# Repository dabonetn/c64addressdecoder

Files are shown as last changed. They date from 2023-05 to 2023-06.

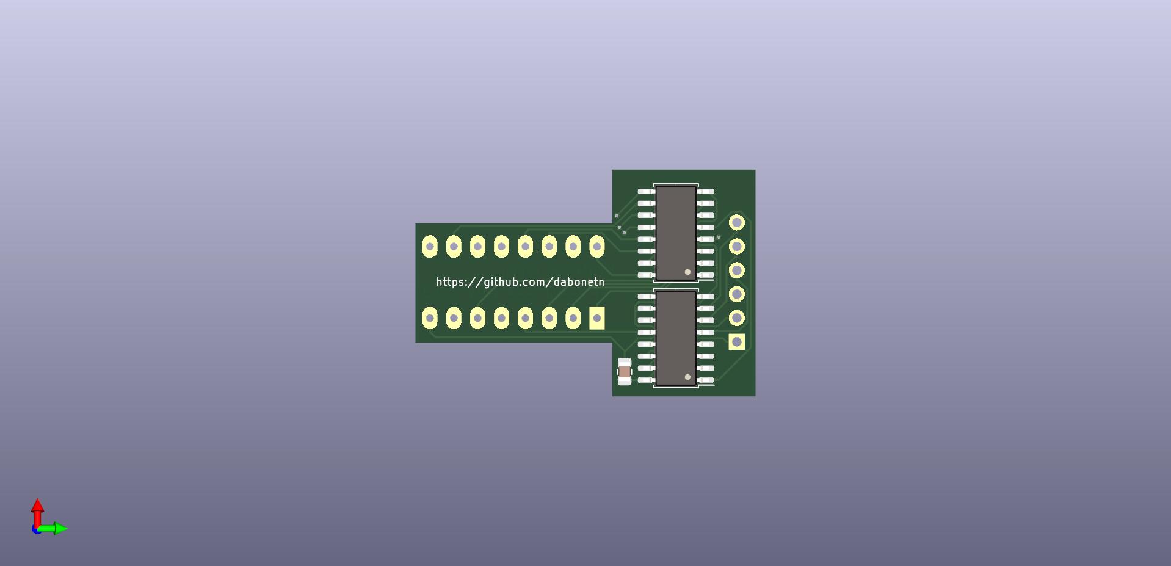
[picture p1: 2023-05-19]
C64 Address Decoder-back.jpg

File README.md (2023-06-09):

# c64addressdecoder
Say hello to my first Kicad project... Time to wean myself off eagle.

Multiple Address Decoder replacement for U15 in C64

This is a D100, D200, D300, D500, D600 & D700 adapter board based on the schematics from Maciej Witkowiak @ https://github.com/ytmytm/c64-ciaide

Goes into a C64 longboard, replacing the 74LS138 at location U15.

These are ready for production at JLCPCB including the 3 surface mount parts. (2x74ls138s and a .1uf cap).

All you need for components are pinheaders for the motherboard socket, and then you can either solder on your wires to the output, or add header pins.

Thanks for Retro Tech Insanity (https://www.youtube.com/@retrotechinsanity3164) for the inspiration.

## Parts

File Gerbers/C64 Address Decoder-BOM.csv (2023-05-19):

Comment | Designator | Footprint | LCSC Part Number
1 | C1 | 0805 | C476766
2 | U2,U3 | SOIC-16 | C521174

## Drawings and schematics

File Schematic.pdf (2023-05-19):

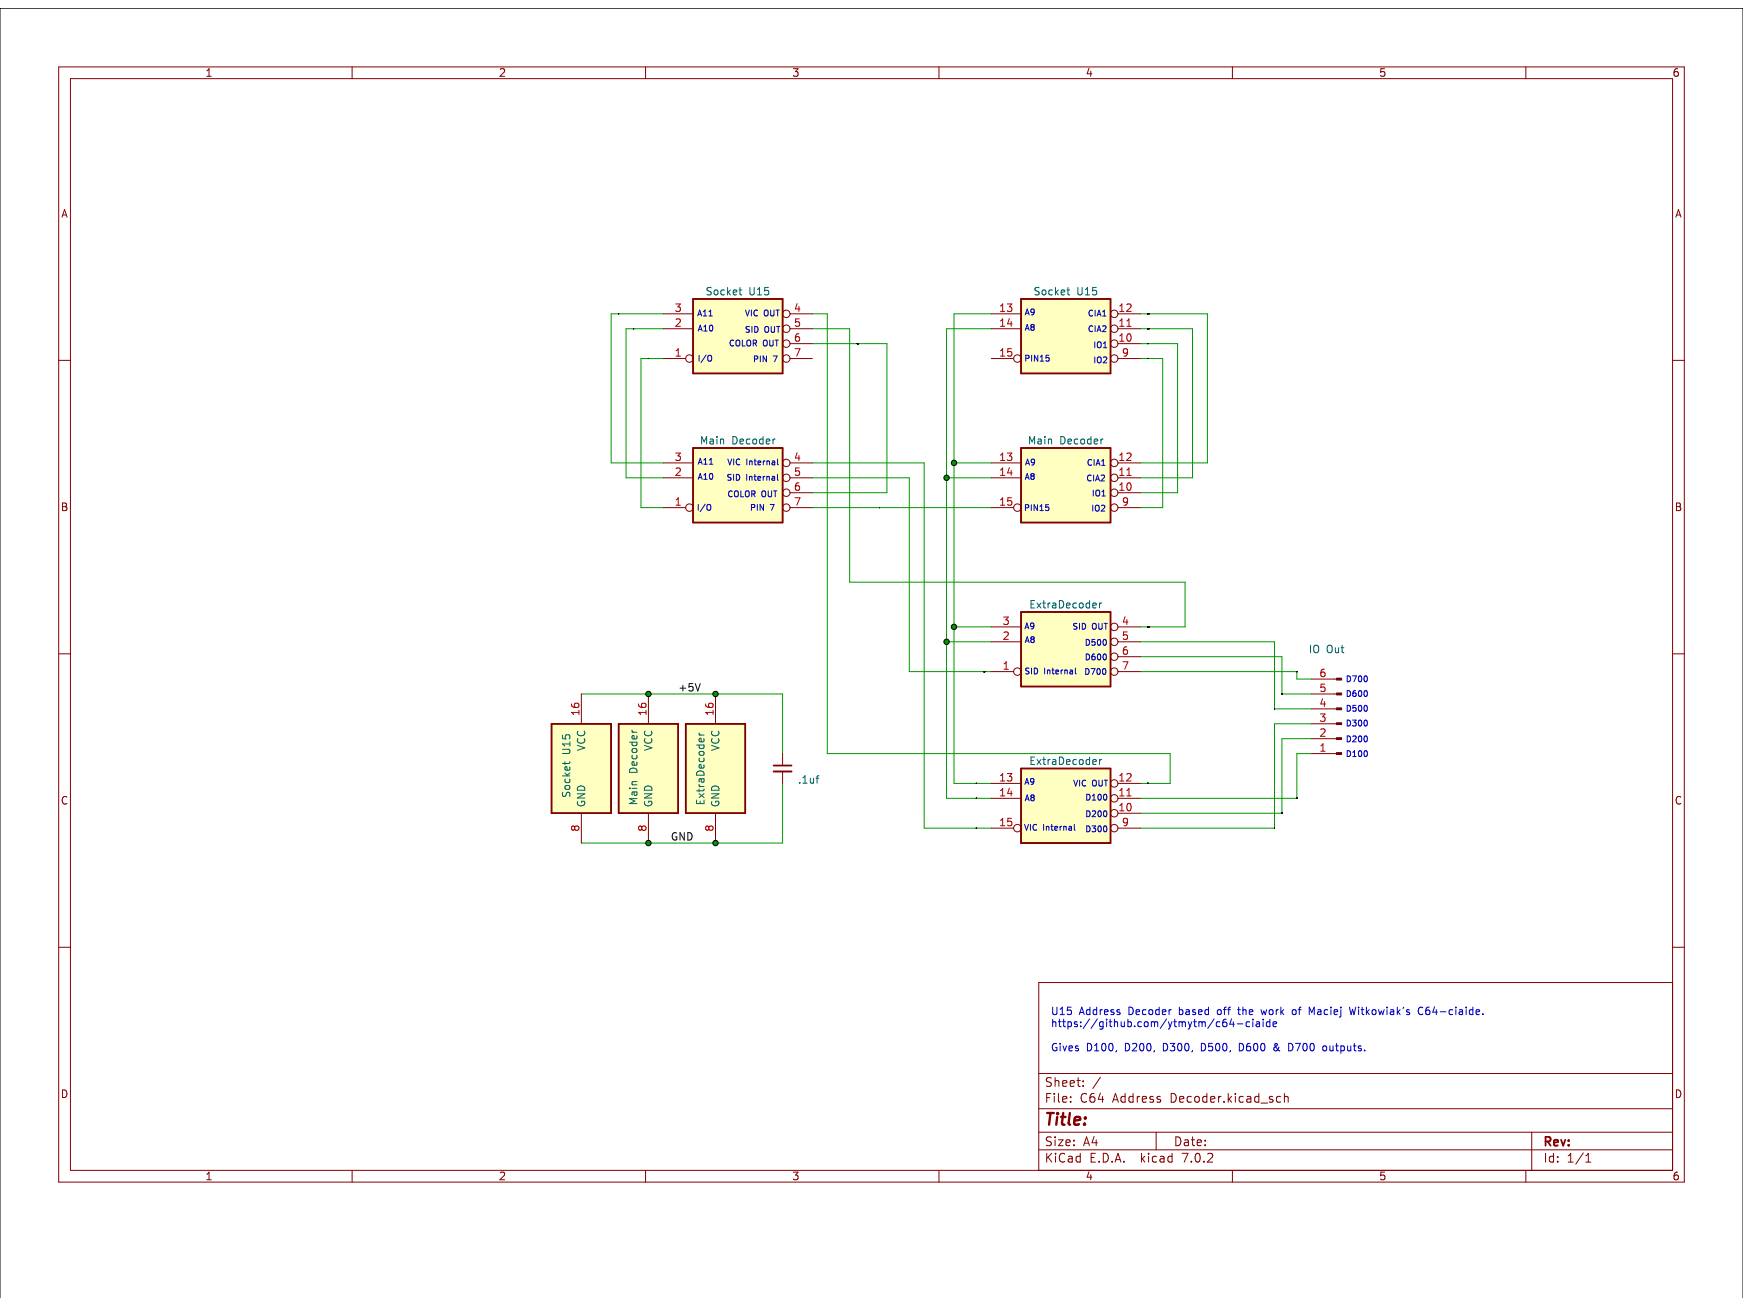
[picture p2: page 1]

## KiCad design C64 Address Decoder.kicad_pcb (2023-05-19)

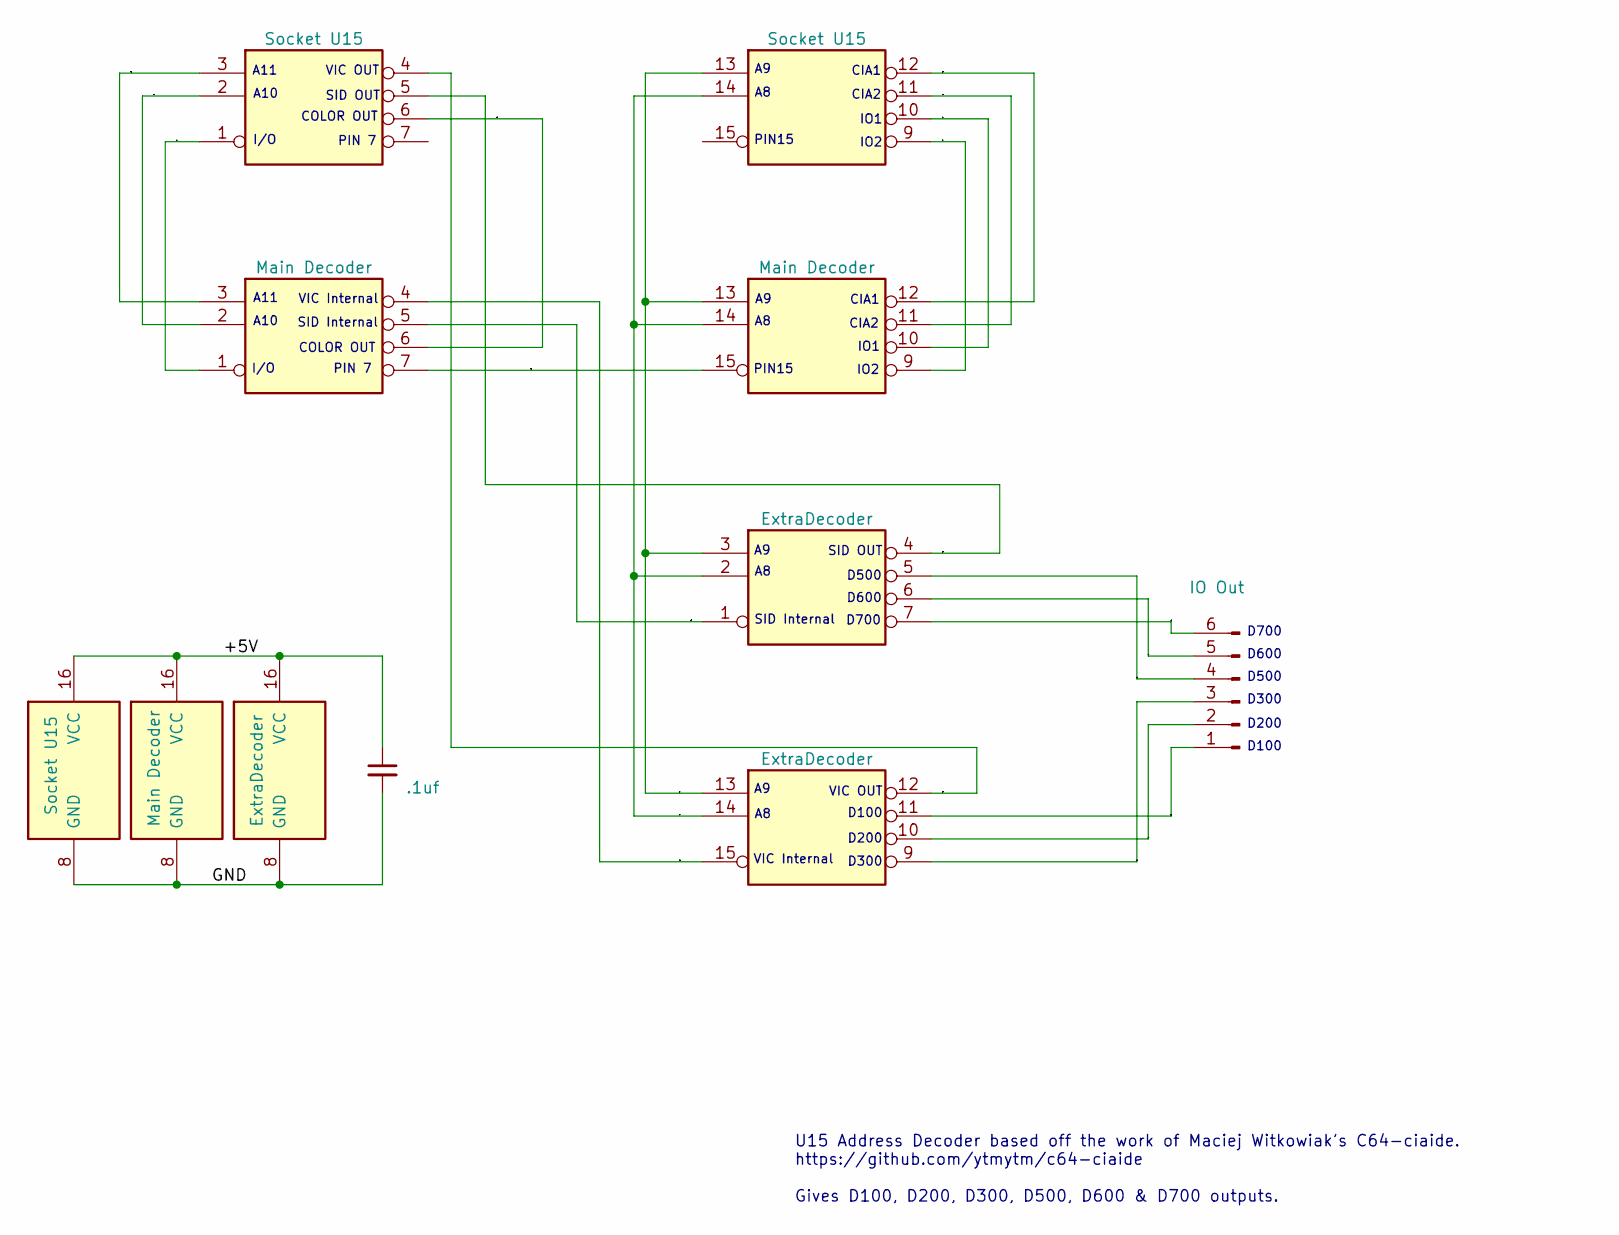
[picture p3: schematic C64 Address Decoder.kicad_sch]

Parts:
C1: .1uf; C_0805_2012Metric; LCSC C779984
J1: IO Out; PinHeader_1x06_P2.54mm_Vertical
U1: Socket U15; DIP-16_W7.62mm_LongPads
U2: Main Decoder; SOIC-16_4.55x10.3mm_P1.27mm; LCSC C521174
U3: ExtraDecoder; SOIC-16_4.55x10.3mm_P1.27mm; LCSC C521174

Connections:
/7TO15: U2.7 (O3), U2.15 (E)
/+5V: C1.1, U1.16 (VCC), U2.16 (VCC), U3.16 (VCC)
/A8: U1.14 (A0), U2.14 (A0), U3.2 (A0), U3.14 (A0)
/A9: U1.13 (A1), U2.13 (A1), U3.3 (A1), U3.13 (A1)
/A10: U1.2 (A0), U2.2 (A0)
/A11: U1.3 (A1), U2.3 (A1)
/CIA1: U1.12 (O0), U2.12 (O0)
/CIA2: U1.11 (O1), U2.11 (O1)
/COLOROUT: U1.6 (O2), U2.6 (O2)
/D100: J1.1, U3.11 (O1)
/D200: J1.2, U3.10 (O2)
/D300: J1.3, U3.9 (O3)
/D500: J1.4, U3.5 (O1)
/D600: J1.5, U3.6 (O2)
/D700: J1.6, U3.7 (O3)
/GND: C1.2, U1.8 (GND), U2.8 (GND), U3.8 (GND)
/IO1: U1.10 (O2), U2.10 (O2)
/IO2: U1.9 (O3), U2.9 (O3)
/I/O: U1.1 (E), U2.1 (E)
/SIDINT: U2.5 (O1), U3.1 (E)
/SIDOUT: U1.5 (O1), U3.4 (O0)
/VICINT: U2.4 (O0), U3.15 (E)
/VICOUT: U1.4 (O0), U3.12 (O0)

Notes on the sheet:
SID OUT
VIC Internal
PIN 7
VIC OUT
COLOR OUT
CIA2
IO1
I/O
D200
U15 Address Decoder based off the work of Maciej Witkowiak's C64-ciaide. https://github.com/ytmytm/c64-ciaide Gives D100, D200, D300, D500, D600 & D700 outputs.
D600
SID Internal
CIA1
D700
A10
IO2
PIN15
D100
A11
D500
D300

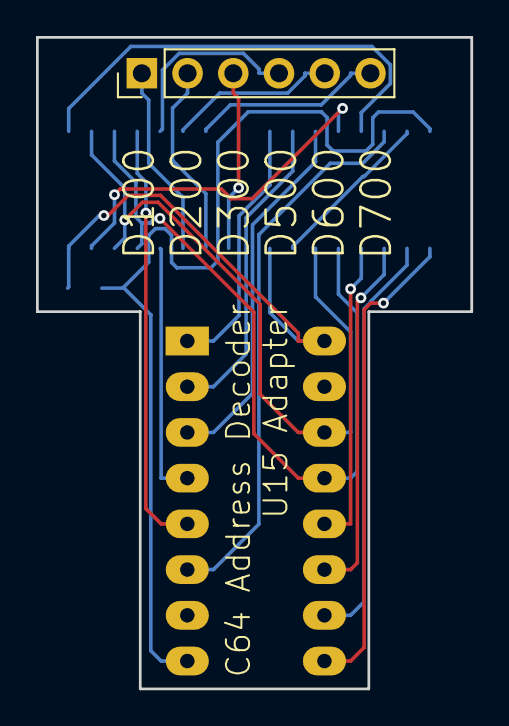
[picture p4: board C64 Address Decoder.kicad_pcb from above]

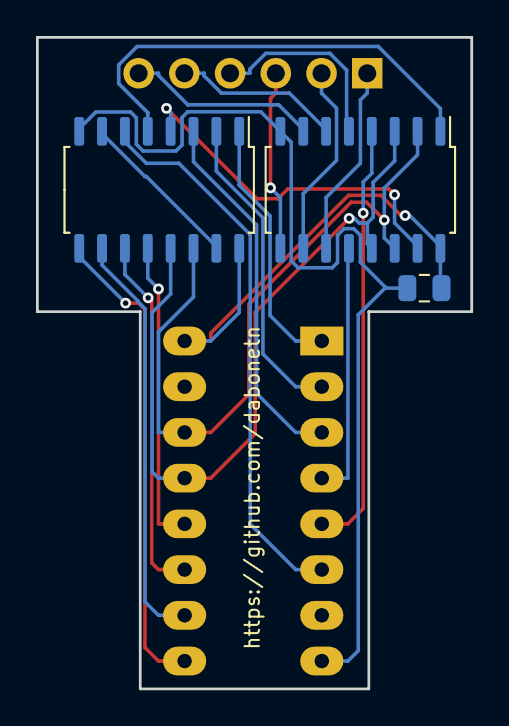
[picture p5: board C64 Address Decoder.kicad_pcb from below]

Board: 2 copper layers, 24.1 x 36.2 mm, 5 parts (3 on the bottom side), 23 nets.

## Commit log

2023-05-19 Initial Upload.
    [C64 Address Decoder-BOM.csv, C64 Address Decoder.kicad_pcb, C64 Address Decoder.kicad_sch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]
2023-06-09 Update README.md
    Boards are tested and working.
